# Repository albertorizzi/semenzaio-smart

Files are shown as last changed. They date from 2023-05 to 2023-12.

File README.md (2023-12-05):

<div align="center">
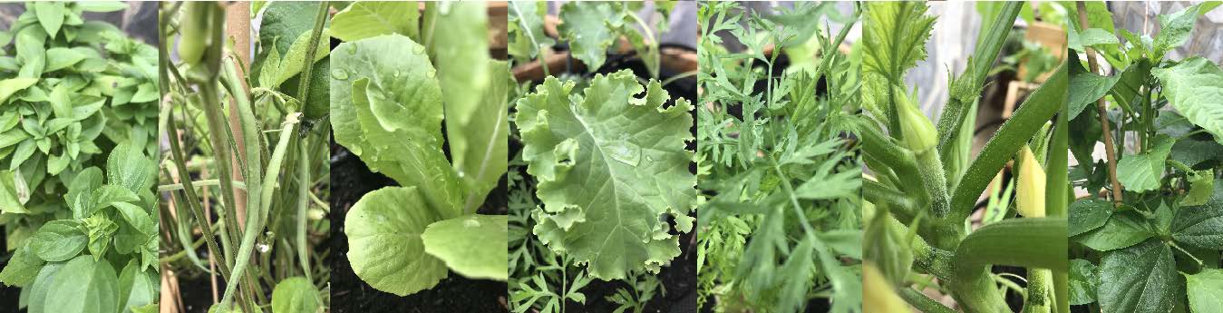
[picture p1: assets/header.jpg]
    
</div>

___

# Semenzaio smart
<div align="center">
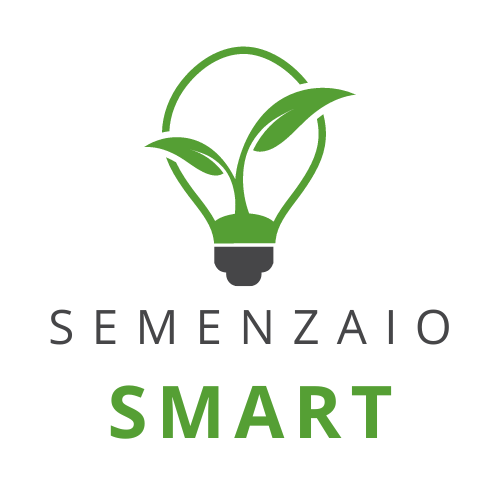
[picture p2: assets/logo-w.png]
    
</div>

**Autori**: Alberto Rizzi, Lorenzo Marcolli

**Link a repo**: https://github.com/albertorizzi/semenzaio-smart

**Licenza scelta**: GNU GENERAL PUBLIC LICENSE version 3 (GPLv3)

**Data *indicativa* di presentazione**: dicembre 2023

## Descrizione
Il progetto prevede la realizzazione di un semenzaio smart mediante l'utilizzo della scheda Arduino® UNO R4 WiFi. Questo dispositivo è in grado di favorire la crescita controllata delle piante di ortaggi, le quali saranno successivamente trapiantate in terra.

All'interno di una mini serra sono stati installati diversi sensori dedicati al monitoraggio di parametri cruciali per lo sviluppo delle piantine, tra cui luminosità, umidità del terreno e temperatura.

Considerando che diverse specie vegetali richiedono condizioni ottimali specifiche per la crescita, i relativi valori sono memorizzati e configurati in un database (Firebase). Questi parametri possono essere regolati attraverso un'App Mobile sviluppata con React Native.

Arduino, durante la fase di setup, acquisirà la configurazione dei valori per la coltura selezionata: mediante i sensori, monitorerà i parametri ambientali e attiverà/spegnerà gli attuatori in base al superamento o no dei valori rispetto alla soglia preimpostata.

Gli attuatori utilizzati sono i seguenti:
- riscaldatore per regolare la temperatura
- pompa per nebulizzare l'acqua per regoare l'umidità del terreno
- lampada per garantire la luminosità necessaria

## Lista materiali
**Componenti hardware**:
- Arduino® UNO R4 WiFi
- Sensore di temperatura e umidità (DHT11)
- Sensore di luminosità (fotoresistenza)
- Modulo relè 4 canali
- Sensore umidità terreno YL-69 e HC-38
- Riscaldatore (resistenza da 80 W, 220 V)
- 2 lampade per fitocoltivazione da 10 W
- Pompa 220 V per nebulizzare acqua
- Ventola da raffreddamento per muovere aria

## Librerie
- `"WiFiSSLClient.h"`
- `"WiFiS3.h"`
- `<ArduinoJson.h>`
- `"DHT.h"`
- `"Arduino_LED_Matrix.h"`

## Circuito
🔗 [Fritzing file](./assets/Semenzaio%20Smart.fzz)

<div align="center">
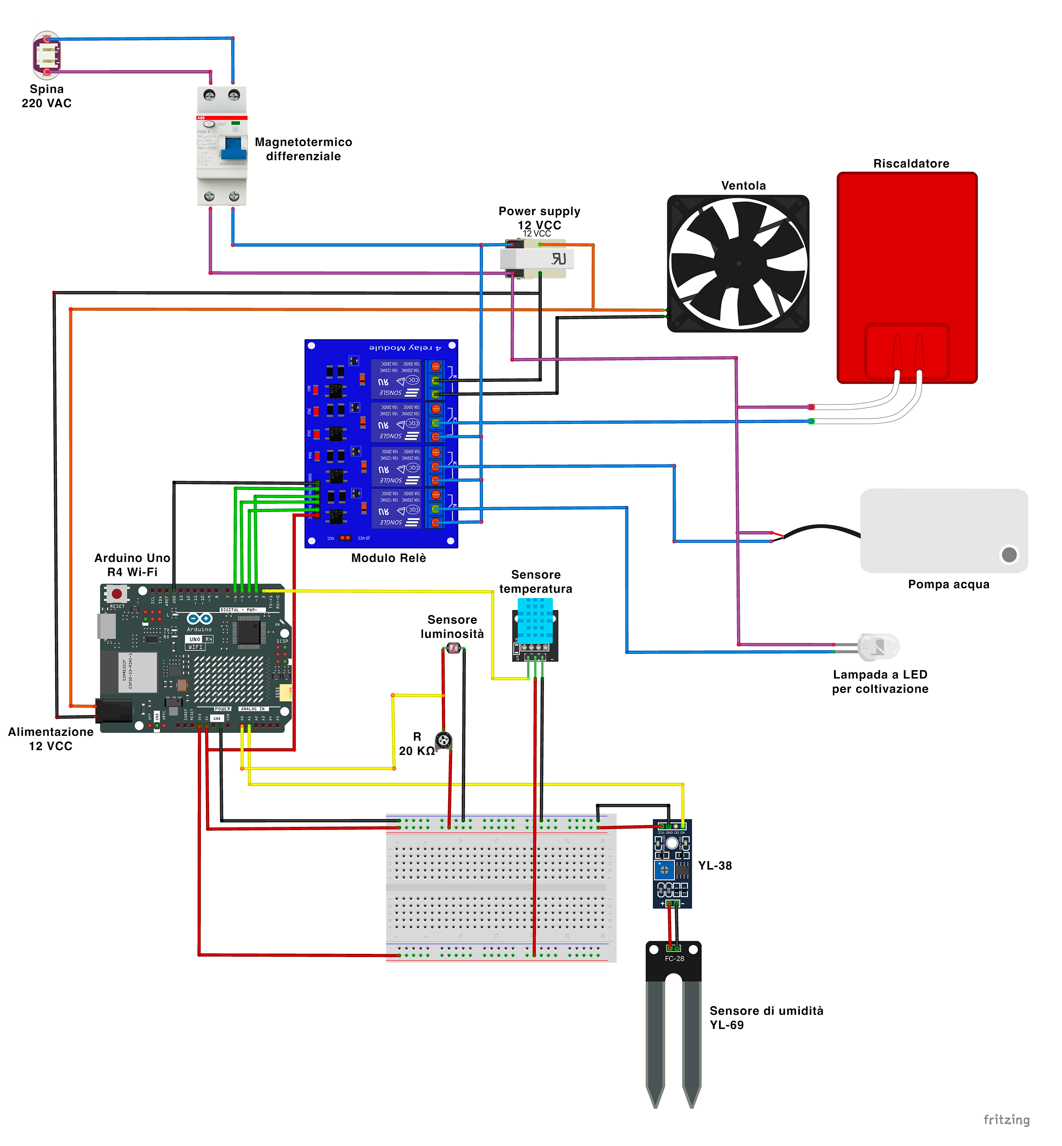
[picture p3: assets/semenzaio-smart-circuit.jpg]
    
</div>

## App
L'app mobile consente di visualizzare i dati in tempo reale, aggiornati ogni 5 secondi, prelevando i valori dalla collezione "logs" di Firebase in tempo reale. Inoltre, offre la possibilità di modificare la coltura e le relative impostazioni, poiché Arduino funge anche da WebServer. Attraverso chiamate HTTP, è possibile controllare l'accensione/spegnimento della ventola e gestire il cambio della coltura.

*Importante*: per ottenere un funzionamento ottimale, è fondamentale che Arduino e il dispositivo mobile siano connessi alla stessa rete Wi-Fi.

<div align="center" style="display:flex; flex-wrap: wrap; justify-content: center;">
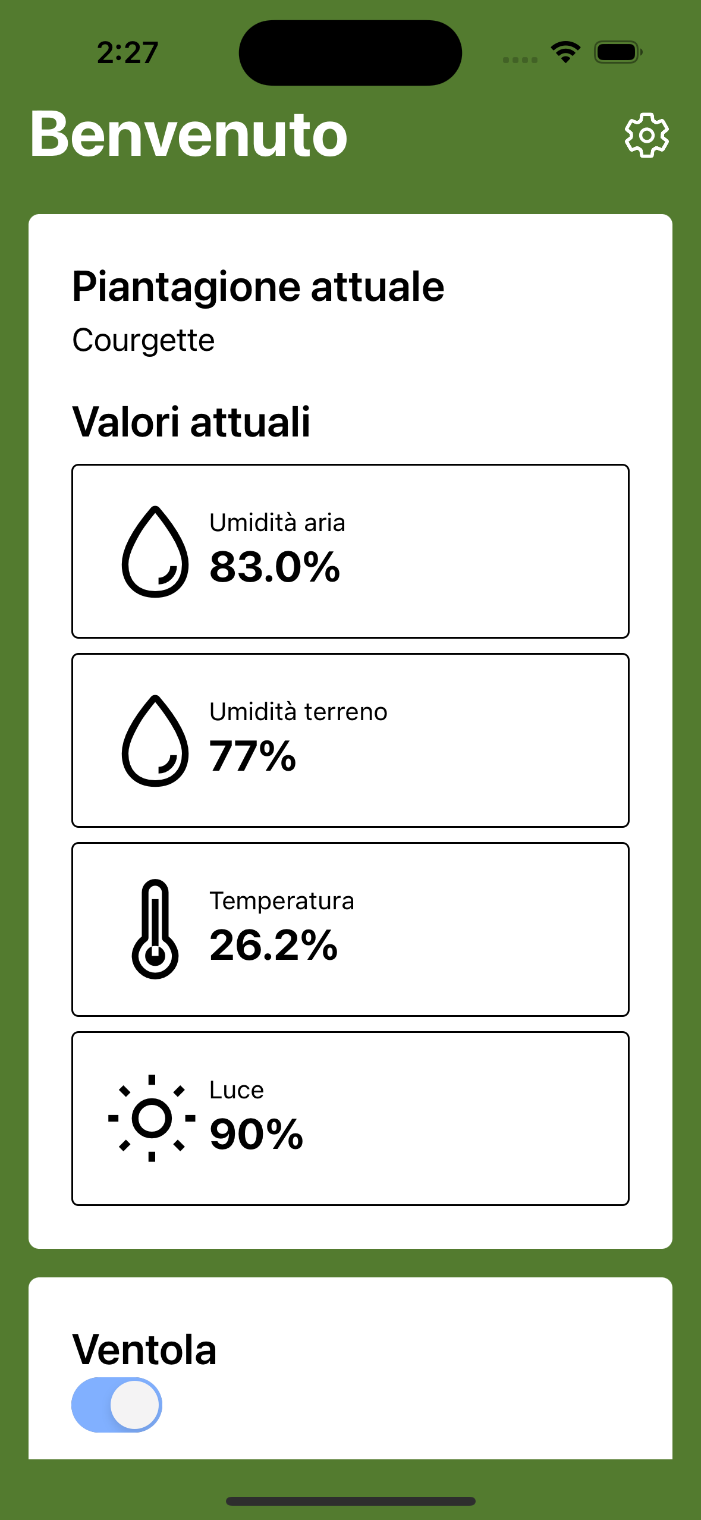
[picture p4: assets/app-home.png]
    
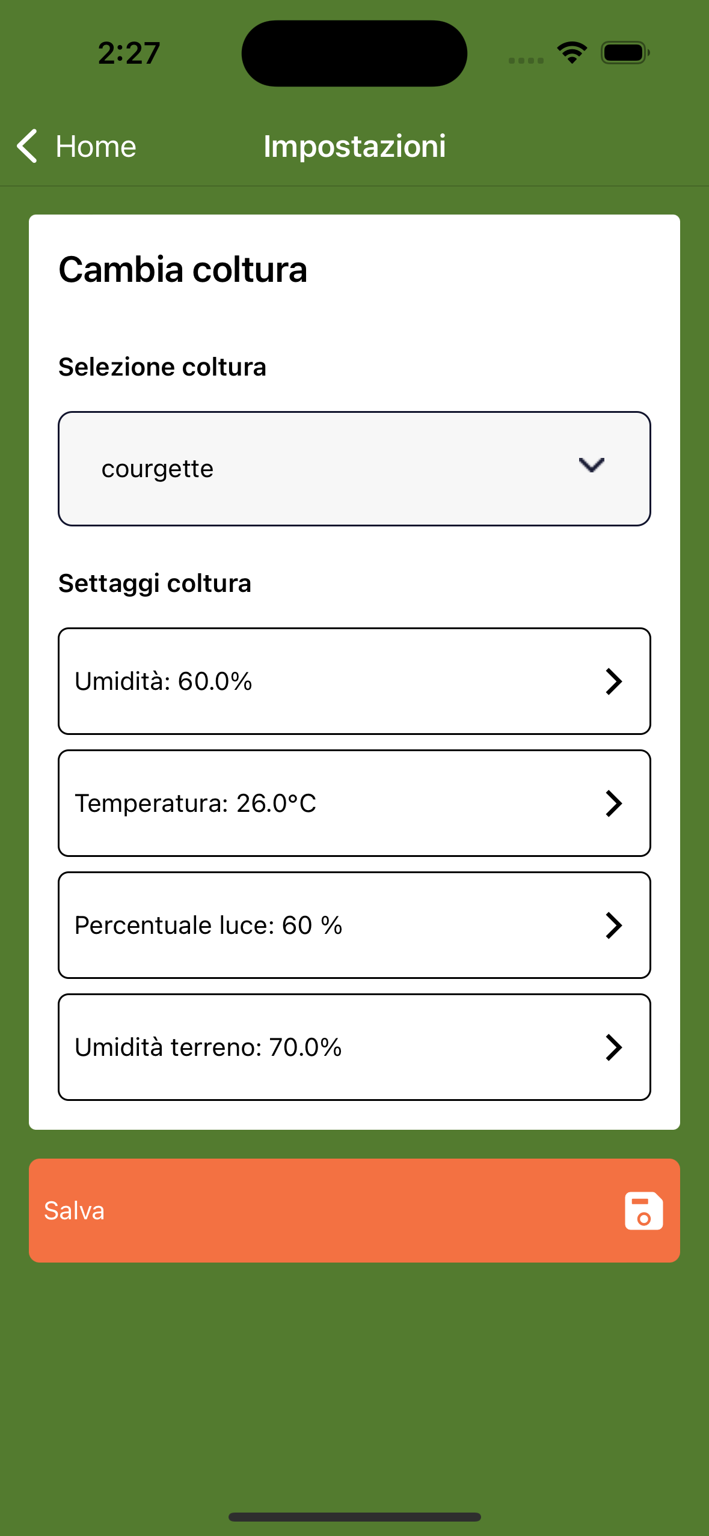
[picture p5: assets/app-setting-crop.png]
    
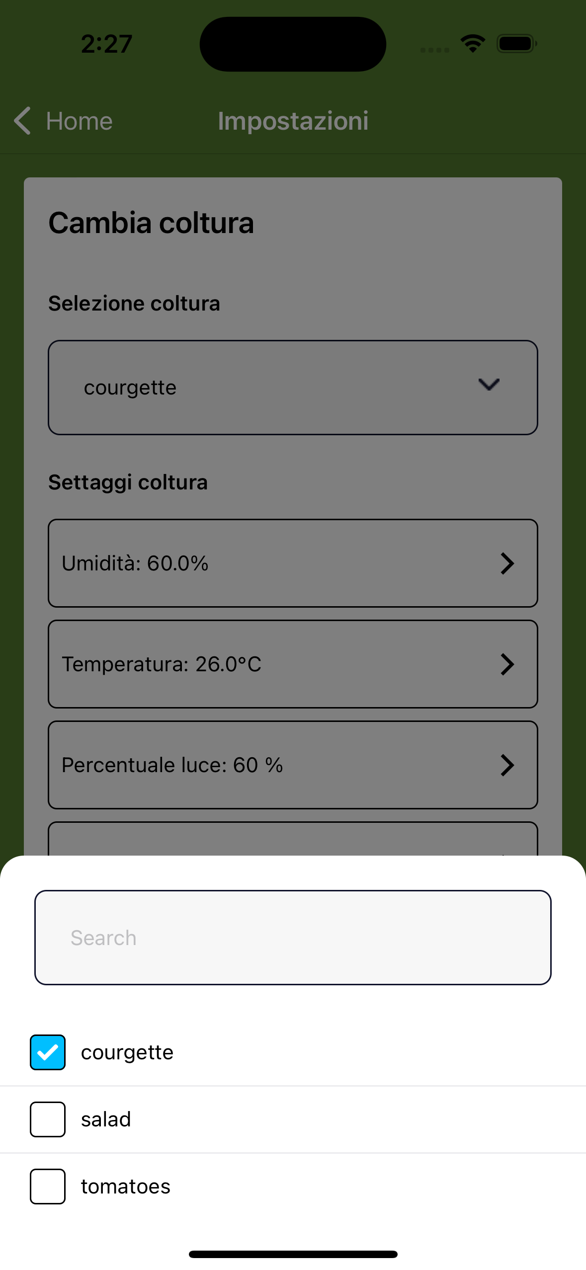
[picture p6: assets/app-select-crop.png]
    
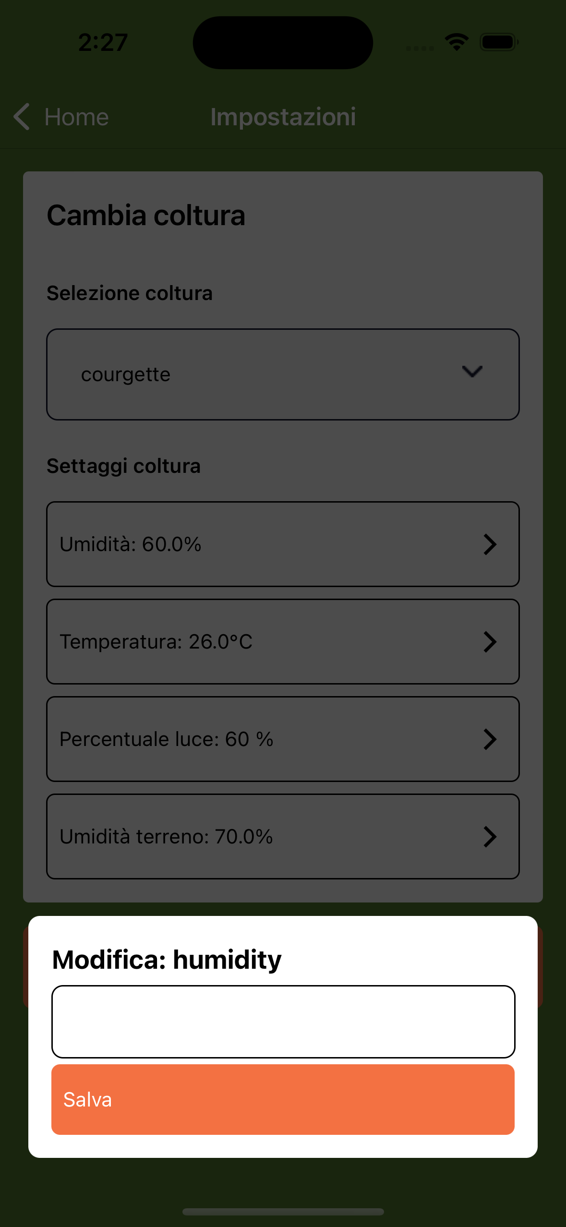
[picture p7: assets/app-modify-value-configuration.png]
    
</div>

## Media
### Semina della coltura

Semina della coltura di pomodori, posizionamento del sensore di umidità del terreno.

<div align="center" style="display:flex; flex-wrap: wrap; justify-content: center;">

Watch the video (https://www.youtube.com/watch?v=oXTzStsKrd4)

</div>

### Cambio coltura
Cambio della coltura attuale tramite la pagina di configurazione dell'app. La nuova coltura necessitando di parametri di luce diversi fa scaturire l'accensione della luce. 

<div align="center" style="display:flex; flex-wrap: wrap; justify-content: center;">

Watch the video (https://www.youtube.com/watch?v=LiDUl17lJrE)

</div>

### Sensore luminosità
Cambiando la luminosità ambientale, il valore di luminosità scende sotto la soglia minimna, pertanto si accende la luce.

<div align="center" style="display:flex; flex-wrap: wrap; justify-content: center;">

Watch the video (https://www.youtube.com/watch?v=DOKdjEj1GwU)

</div>

### Accesione pompa
Cambiando i parametri necessari di umidità del suono, viene suparata la soglia minima della coltura attuale, pertanto si accende la pompa per nebulizzare l'acqua.

<div align="center" style="display:flex; flex-wrap: wrap; justify-content: center;">

Watch the video (https://www.youtube.com/watch?v=_HplzdNERQg)

</div>

### Accensione ventola
Cambiando il valore ON/OFF sulla App Mobile, si accende e spegne la ventola.

<div align="center" style="display:flex; flex-wrap: wrap; justify-content: center;">

Watch the video (https://www.youtube.com/watch?v=NtAnDMgpZjI)

</div>

### Fasi della crescita della coltura del pomodoro
Fotogrammi relativi alla crescita della coltura del pomodoto in ambiente controllato, 7 giorni.

<div align="center" style="display:flex; flex-wrap: wrap; justify-content: center;">

Watch the video (https://www.youtube.com/watch?v=yn9_0HByvpk)

</div>

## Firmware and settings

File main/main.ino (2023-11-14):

#include "WiFiSSLClient.h"
#include "WiFiS3.h"
#include <ArduinoJson.h>
#include "DHT.h"
#include "arduino_secrets.h"
#include "Arduino_LED_Matrix.h"

#include "models.h"

// #include "utils.h"
#include "firebase.h"
#include "connectionWifiManager.h"
#include "read_temp_hum.h"
#include "readLuminosity.h"
#include "readHygrometer.h"



WiFiServer server(80);



void setup() {

  //Initialize serial and wait for port to open:
  Serial.begin(9600);
  while (!Serial) {
    ;  // wait for serial port to connect. Needed for native USB port only
  }

  pinMode(HEATER_PIN, OUTPUT);
  pinMode(LIGHT_PIN, OUTPUT);
  pinMode(PUMP_PIN, OUTPUT);
  pinMode(FAN_PIN, OUTPUT);

  pinMode(LED_BUILTIN, OUTPUT);



  wifiConnection();

  // getConfiguration first time
  getConfiguration();

  // initializa sensors
  dht.begin();

  // active web server
  server.begin();
  matrix.begin();

    // ventola, PIN digital 6
  // sempre accesa per garantire che non ristagni unimità
  digitalWrite(FAN_PIN, ReleStatus::ON);

  // Tutti i relè spenti 
  digitalWrite(PUMP_PIN, ReleStatus::OFF);
  digitalWrite(LIGHT_PIN, ReleStatus::OFF);
  digitalWrite(LIGHT_PIN, ReleStatus::OFF);
}

void loop() {
  webServerManager();
  readSensors();
  manageActuators();
  sendLogSensors();

  delay(5000);
}

void readSensors() {

  // Temperature
  readTempHum();

  readLuminosity();

  readHygrometer();
}

void manageActuators() {
  // riscaldatore PIN Digital 3
  // se temperatura maggiore di quella della cultura allora spengo riscaldatore
  if (sensorsValue.tempHum.temp > cropConfiguration.temperature) {
    digitalWrite(HEATER_PIN, ReleStatus::OFF);
  } else {
    digitalWrite(HEATER_PIN, ReleStatus::ON);
  }

  // ligth percentage, PIN digital 4
  // se umidità suolo è maggiore di quella della cultura, allora spengo pompa
  Serial.print(cropConfiguration.lightPercentage);


  if (sensorsValue.luminosity > cropConfiguration.lightPercentage) {
    digitalWrite(LIGHT_PIN, ReleStatus::OFF);
  } else if (sensorsValue.luminosity < cropConfiguration.lightPercentage) {
    digitalWrite(LIGHT_PIN, ReleStatus::ON);
  }


  // umidità suolo, PIN digital 5
  // se umidità suolo è maggiore di quella della cultura, allora spengo pompa
  if (sensorsValue.soilMoisture > cropConfiguration.soilHumidity + 2) {
    digitalWrite(PUMP_PIN, ReleStatus::OFF);
  } else if (sensorsValue.soilMoisture < cropConfiguration.soilHumidity - 2) {
    digitalWrite(PUMP_PIN, ReleStatus::ON);
  }


}

void webServerManager() {
  WiFiClient client = server.available();  // listen for incoming clients

  if (client) {                    // if you get a client,
    Serial.println("new client");  // print a message out the serial port
    String currentLine = "";       // make a String to hold incoming data from the client
    while (client.connected()) {   // loop while the client's connected
      if (client.available()) {    // if there's bytes to read from the client,
        char c = client.read();    // read a byte, then
        Serial.write(c);           // print it out to the serial monitor
        if (c == '\n') {           // if the byte is a newline character

          // if the current line is blank, you got two newline characters in a row.
          // that's the end of the client HTTP request, so send a response:
          if (currentLine.length() == 0) {
            // HTTP headers always start with a response code (e.g. HTTP/1.1 200 OK)
            // and a content-type so the client knows what's coming, then a blank line:

            // break out of the while loop:
            break;
          } else {  // if you got a newline, then clear currentLine:
            currentLine = "";
          }
        } else if (c != '\r') {  // if you got anything else but a carriage return character,
          currentLine += c;      // add it to the end of the currentLine
        }

        // Check to see if the client request was "GET /H" or "GET /L":
        if (currentLine.endsWith("GET /configuration")) {
          Serial.println("configuration");  // GET /H turns the LED on

          getConfiguration();

          client.println("HTTP/1.1 200 OK");
          client.println("Content-type:text/html");
          client.println();

          // the content of the HTTP response follows the header:
          client.print(cropConfiguration.temperature);

          // The HTTP response ends with another blank line:
          client.println();

          Serial.println(cropConfiguration.temperature);
        }
        if (currentLine.endsWith("GET /fan/ON")) {
          Serial.println("FAN ON");
          digitalWrite(FAN_PIN, ReleStatus::ON);
          matrix.loadFrame(happy);

          client.println("HTTP/1.1 200 OK");
          client.println("Content-type:text/html");
          client.println();
        }

        if (currentLine.endsWith("GET /fan/OFF")) {
          Serial.println("FAN OFF");
          digitalWrite(FAN_PIN, ReleStatus::OFF);
          matrix.loadFrame(heart);

          client.println("HTTP/1.1 200 OK");
          client.println("Content-type:text/html");
          client.println();
        }
      }
    }
    // close the connection:
    client.stop();
    Serial.println("client disconnected");
  }
}

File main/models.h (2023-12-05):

struct Crop {
  int temperature;
  int humidity;
  int soilHumidity;
  int lightPercentage;
};

struct Configuration {
  String ipAddress;               // Assuming IPv4 address, change size if needed
  Crop currentCropConfiguration;  // Assuming a maximum of 10 tomato crops, adjust as needed
  String currentCrop;             // Adjust size as needed
};

struct TempHum {
  float temp;
  float hum;
};


struct SensorsValue {
  TempHum tempHum;
  int luminosity;
  int soilMoisture;
};

Crop cropConfiguration;

WiFiSSLClient client;

SensorsValue sensorsValue;

ArduinoLEDMatrix matrix;


// sensors
// PIN TEMP AND HUM
#define DHTPIN 2
#define DHTTYPE DHT11

#define LUMINOSITYPIN A0

#define HYGROMETERPIN A1

#define HEATER_PIN 3
#define LIGHT_PIN 4
#define PUMP_PIN 5
#define FAN_PIN 6



#define MAX_VALUE_LUMINOSITY 1024
#define MIN_VALUE_LUMINOSITY 5

DHT dht(DHTPIN, DHTTYPE);

enum ReleStatus {
  ON = LOW,
  OFF = HIGH
};

const uint32_t happy[] = {
  0x19819,
  0x80000001,
  0x81f8000
};
const uint32_t heart[] = {
  0x3184a444,
  0x44042081,
  0x100a0040
};

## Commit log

2023-10-10 ci: add luminosity, soil moisture sensors
2023-11-14 ci: finish arduino develop
2023-11-21 ci: finish readme
    [Semenzaio Smart.fzz]
2023-11-22 ci: change circuit image
    [Semenzaio Smart.fzz]
2023-12-05 ci: fix resistance
    [Semenzaio Smart.fzz]
